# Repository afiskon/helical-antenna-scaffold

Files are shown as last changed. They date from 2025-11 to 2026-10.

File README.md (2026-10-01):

# Helical Antenna Scaffold and Calculator

This is a fork of 3D printable helical antenna scaffold implemented
by [@sgcderek][1] in 2021-2023.

One major difference from the original is that this project has a built-in
helical antenna calculator. The calculation method is based on the
[book by Igor, DL2KQ][2]. You only specify the desired frequency and optionally
other parameters. The math is done by OpenSCAD.

Besides that you can specify as many struts as you want and make them
symmetrical along the Z axis. This is useful when printing large antennas
in two or more parts and then gluing them.

Also this repository includes:

* An antenna cover and LNB mount for QO-100 operation. The models are
  optimized for Bullseye LNB.
* Reflector model for helicone antenna, designed according to the paper
  [Design of Optimal Ground Conductor for the Helical Antenna][3].

Note that optimal parameters for helicone and helical antenna differ.
See the list of related articles, particularly #5.

Related articles (in Russian):

1. https://eax.me/2025/2025-10-20-helical-antenna.html
2. https://eax.me/2025/2025-11-21-qo-100-tx.html
3. https://eax.me/2026/2026-08-05-helicone-antenna.html
4. https://eax.me/2026/2026-09-02-meteor-m2-hrpt.html
5. https://eax.me/2026/2026-09-09-helicone-antenna-modeling.html
6. https://eax.me/2026/2026-09-16-metop.html

[1]: https://github.com/sgcderek
[2]: http://dl2kq.de/ant/kniga/1345.htm
[3]: http://home.etf.rs/~milanilic/publications/papers/Djordjevic-Etran06.pdf

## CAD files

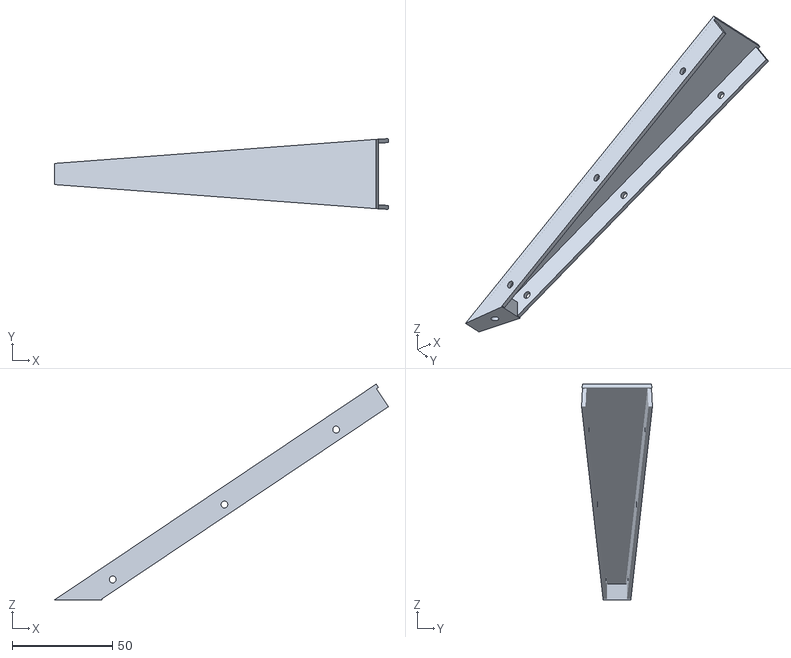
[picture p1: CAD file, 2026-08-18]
stl-files/meteor-m2/helicone-reflector-1700mhz.stl
166.2 x 35.3 x 107.4

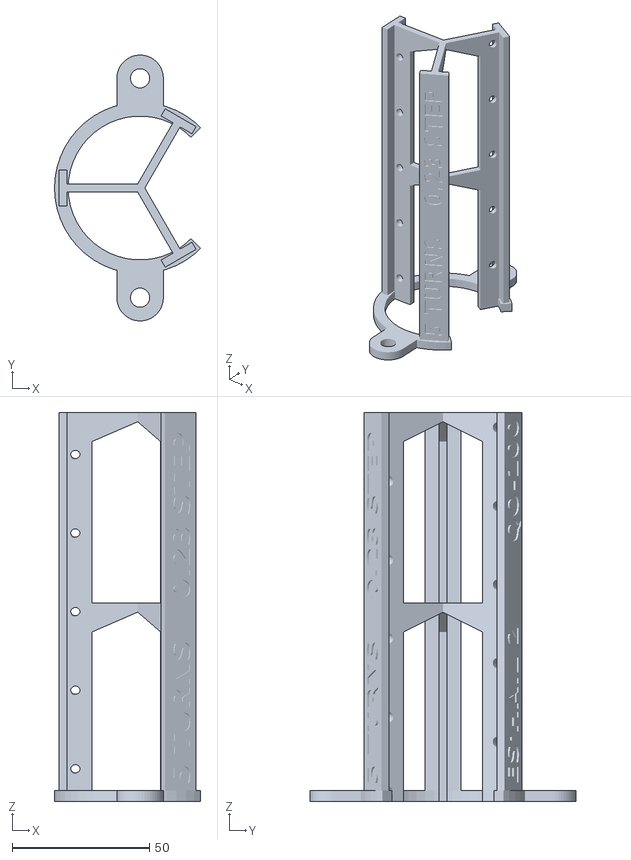
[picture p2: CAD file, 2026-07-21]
stl-files/qo-100/scaffold-qo-100.stl
53.3 x 97.0 x 141.9

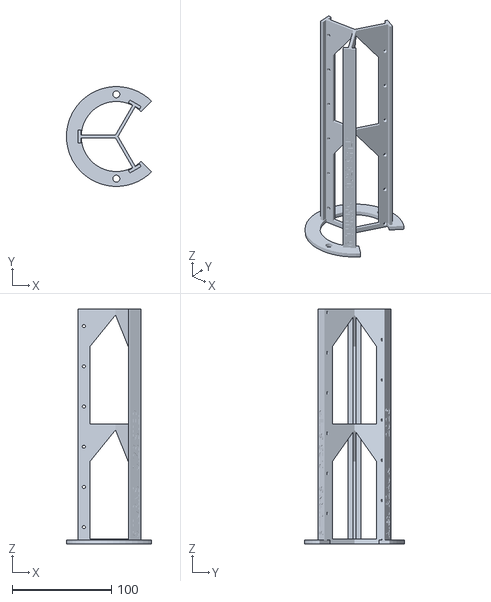
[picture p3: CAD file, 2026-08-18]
stl-files/meteor-m2/helical-antenna-1700mhz.stl
85.9 x 100.5 x 236.9

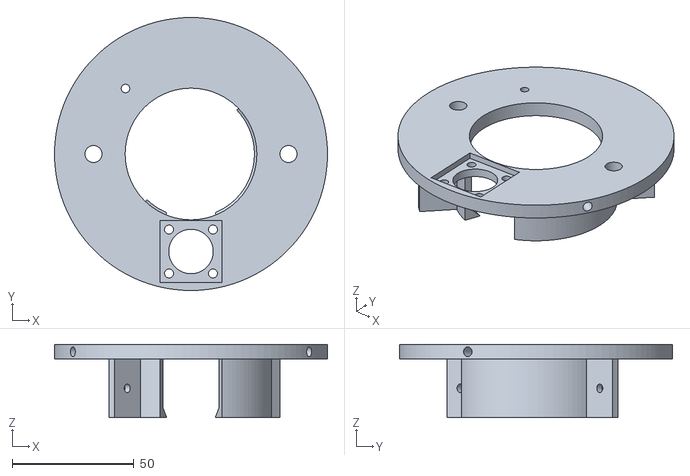
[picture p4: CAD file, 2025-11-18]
stl-files/qo-100/base.stl
112.0 x 112.0 x 30.0

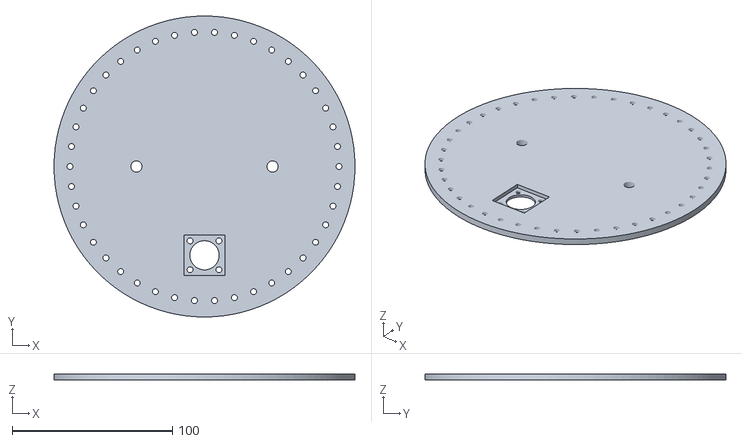
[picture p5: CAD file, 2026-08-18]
stl-files/meteor-m2/helicone-base-1700mhz.stl
187.8 x 187.8 x 4.00

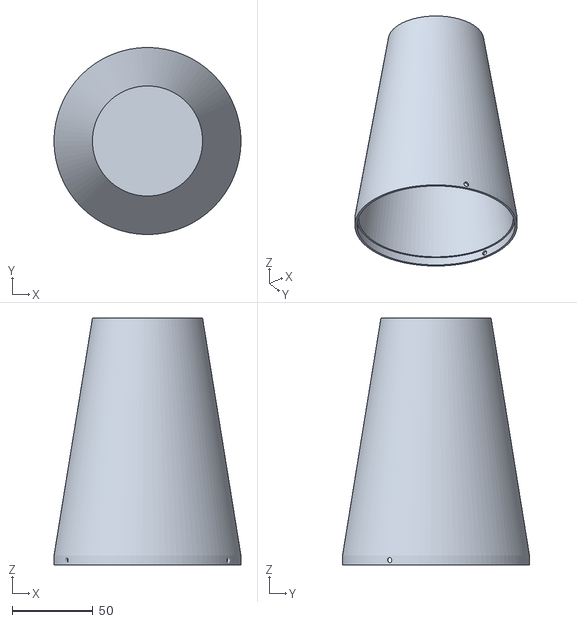
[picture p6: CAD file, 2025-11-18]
stl-files/qo-100/cover.stl
115.4 x 115.4 x 152.5

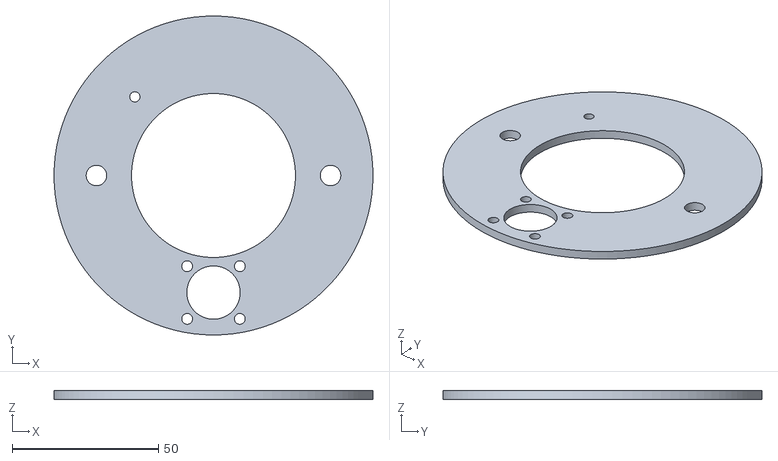
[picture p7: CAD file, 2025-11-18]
stl-files/qo-100/cutting-template.stl
109.0 x 109.0 x 3.00

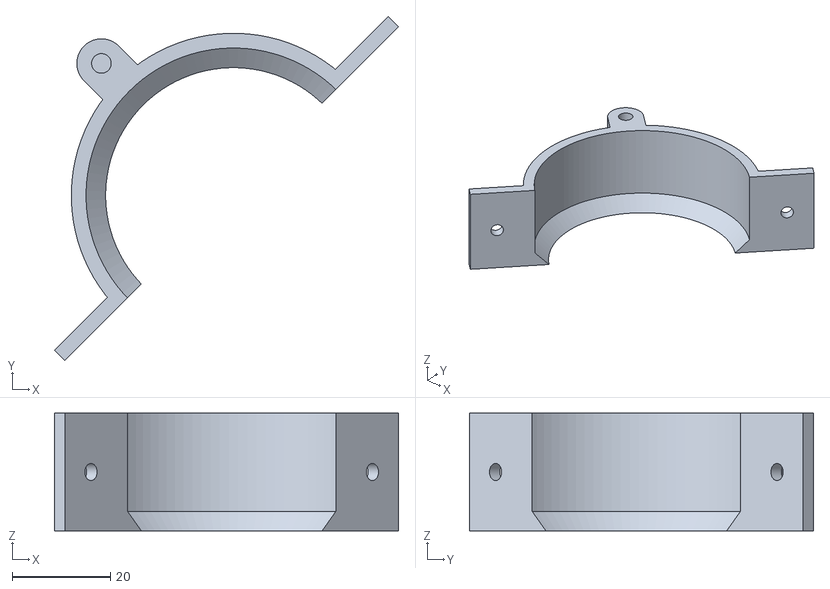
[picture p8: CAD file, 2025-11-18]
stl-files/qo-100/clamp.stl
70.0 x 70.0 x 24.0

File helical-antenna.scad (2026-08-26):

/*
 * dereksgc customizable helical antenna scaffold v5
 *   https://github.com/sgcderek/dsgc-helix-scaffold/
 *
 * Modified by Alex, R2AUK
 *   https://github.com/afiskon/helical-antenna-scaffold
 */

/* [Basic settings] */

// Operating frequency of the helix (MHz)
Frequency = 2450;

// Spacing between turns (wl)
Spacing = 0.23; // [0.22..0.24]

// Number of turns of the helix
Turns = 5; // [3..25]

// Vertical offset of the first (bottom) hole (mm)
Bottom_hole_offset = 2.5;

// Polarization of the helix
Polarization = "LHCP"; //[RHCP,LHCP]

// Diameter of the holes for the helix conductor (mm)
Cutout_diameter = 3.5;

// Face number (OpenSCAD/Customizer parameter)
$fn = 50;

/* [Leg settings] */

// Width of the inner leg wall (mm)
Inner_leg_width = 3;

// Width of the outer leg wall (mm)
Outer_leg_width = 13;

// Distance between inner and outer leg walls (mm)
Leg_wall_distance = 12;

// Type of leg cross-section to extrude
Leg_type = "T-Beam"; //[Trapezoid,T-Beam,H-Beam]

/* [Base settings] */

// Base width (mm)
Base_width = 5;

// Base thickness (mm)
Base_thickness = 4;

// Cut out a third of the base (space for matching, connector, etc.)
Enable_cutout = true;

/* [Strut settings] */

// Angle at which struts are generated (deg)
Strut_angle = 60;

// Generate a strut at the base of the scaffold
Bottom_strut = true;

// How much to shift the bottom strut up (mm)
Bottom_strut_offset = 0;

// Total number of struts above the base (minimum 1, top strut is included)
Struts_number = 2;

// Make middle struts symmetrical along the Z axis with X-shaped overhangs
Symmetrical_struts = false;

// Generate a strut at the top of the scaffold (recommended for most scaffolds)
Top_strut = true;

// How much to shift the top strut down (mm)
Top_strut_offset = 0;

/* [Mounting settings] */

// Distance between the two mounting holes (mm)
Mounting_separation = 70;

// Diameter of the mounting holes (mm)
Mounting_diameter = 7;

// Thickness of the rim around each mounting hole (mm)
Mounting_thickness = 5;

// Rotational offset of the mounting holes (deg)
Mounting_rotation = 0;

/* [Text settings] */

// Enable engraved ID and decoration text
Enable_text = true;

// Custom decoration text (set to none to disable)
Decoration_text = "Alex R2AUK        2026";

// Depth of the text engraving (mm)
Text_depth = 0.75;

// Modifies the size of the text (can be lowered if text is too long)
Text_size_multiplier = 0.8;

/* [Hidden] */

// Polarization modifier (RHCP = 1, LHCP = -1)
Pol_modifier = (Polarization == "RHCP") ? 1 : -1;

// Speed of light (m/s)
C = 299792458;

// Wavelength of the helix frequency (mm)
Wavelength = C/Frequency/1000;

// Gain and diameter are determined using approximations of the plots
// provided by Igor, DL2KQ http://dl2kq.de/ant/kniga/1345.htm
Gain = (-0.18*pow(Turns, 2) + 0.57*Turns - 12.63) * exp(-0.16 * Turns) + 19;
echo(str("Approximate gain: ", ceil(Gain * 10) / 10, " dBi"));

// Diameter of the helix (wl)
Diameter_wl = ceil((0.2467 * pow(Turns, -0.2666) + 0.2172)*1000)/1000;

// Diameter of the helix (mm)
Diameter = ceil(Wavelength * Diameter_wl * 10) / 10;
echo(str("Helix diameter: ", Diameter_wl, " wl, ", Diameter, " mm"));

Wire_length = ceil(Diameter * PI * Turns);
echo(str("Approximate wire length: ", Wire_length, " mm"));

Refl_round_dia = ceil(0.8 * Wavelength);
echo(str("Round reflector diameter: ", Refl_round_dia, " mm"));

Refl_square_size = ceil(1.1 * Wavelength);
echo(str("Square reflector size: ", Refl_square_size, " mm"));

ra_to_wire_dia_wl = [
    [240, 0.005],
    [190, 0.01],
    [140, 0.02],
    [115, 0.03],
    [87,  0.04],
    [75,  0.05],
    [50,  0.07],
];

for(item = ra_to_wire_dia_wl) {
    ra = item[0];
    dia = ceil(item[1] * Wavelength * 10)/10;
    echo(str("Wire diameter for ", ra, " Ohm input impedance: ", dia, " mm"));
}

// Distance between turns (mm)
Spacing_distance = Wavelength*Spacing;

// Circumference of the helix (mm)
Circumference = PI*Diameter;

// Helix pitch (deg)
Pitch = atan(Spacing_distance/Circumference)*Pol_modifier;

// Calculate total number of segments in helix
Total_segments = Turns * 3;

// Calculate the length of each segment (slightly longer than longest leg dimension, mm)
Segment_height = max(Inner_leg_width, Outer_leg_width)*1.1;

// Calculate offset of the bottom corner of the strut base from the desired overhang angle
Strut_offset = ((Diameter/2)/tan(Strut_angle))-Leg_wall_distance/2;

// Total scaffold height (mm)
Total_height = Bottom_hole_offset + Turns * Spacing_distance + Cutout_diameter * 1.5;

echo(str("Total scaffold height: ", Total_height, " mm"));

// Thicknes of the top part of each strut (mm)
Strut_thickness = 3; // Total_height;

// Font used for the text on the leg
Text_font = "DejaVu Sans:style=Bold";

// Size of the text
Text_size = Outer_leg_width*0.75*Text_size_multiplier;

// Frequency text
Text_frequency = str(Frequency, " MHz          ", Polarization /*, " ", Material*/);

// Diameter, Pitch
Text_ID = str("Dia ", round(Diameter_wl*100)/100, "   Pitch ", round(Spacing*100)/100);

// Difference between legs and leg cutouts
difference(){
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

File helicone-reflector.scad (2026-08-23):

F_MHz = 2450;
Lambda_mm = (299792458 / (F_MHz*1000000))*1000;
max_width = 25;       // Maximum allowed width of the larger trapezoid base (mm)

mounting_holes_dia = 7;   // see helical-antenna.scad, Mounting_diameter
mounting_separation = 70; // see helical-antenna.scad, Mounting_separation

// Make sure the bottom N-gon does not collapse inside the D1 circle
// The value 10 works OK for F_MHz in 1691..2450 range
// Set to 0 if preserving ideal cone angles is more important
d1_correction = 10;

// You can also experiment with D2 correction
// Personally I doubt that it affects much the overall antenna gain
d2_correction = 0;

D1 = Lambda_mm*0.782 + d1_correction; // Bottom diameter (mm)
D2 = Lambda_mm*2.604 + d2_correction; // Top diameter (mm, D2 > D1)
H = Lambda_mm*0.6;    // Cone height (mm)
t = 2;                // Wall and flange thickness (mm)

gap = 0.1;        // Gap between adjacent trapezoid segments (mm)
eps = 0.05;       // Small overlap for clean CSG boolean operations

// Side Flange Parameters
flange_w = 10;    // Side flange width (mm)
screw_d  = 3.5;   // Side screw hole diameter (mm, for M3)
edge_offset = 28;  // Offset from edges to outer holes (mm)
flange_inset = 1.5; // Radial inset towards Z-axis for full wall intersection (mm)

// Bottom Outer Mount Flange Parameters
bottom_h = 8;            // Height/thickness of the bottom mounting flange (mm)
bottom_flange_w = 20;    // Width of the bottom flange extending outward (mm)
insert_d = 3.7;          // Hole diameter for heat-set insert (mm)

$fn = 100;

// =================================================================
// GEOMETRY CALCULATIONS
// =================================================================

ratio = min(1, max_width / D2);
N_calc = ceil(180 / asin(ratio));
N = max(3, N_calc);
step_angle = 360 / N;

echo(str("Calculated number of facets N = ", N));

alpha = atan((D2 - D1) / (2 * H)); // Wall tilt angle relative to vertical
t_rad = t / cos(alpha);            // Radial thickness of the wall

half_angle = step_angle / 2;

// =================================================================
// MODULES
// =================================================================

// Main trapezoidal wall segment of the cone
module main_wall_segment() {
    r1_out = D1 / 2;
    r1_in  = r1_out - t_rad;
    r2_out = D2 / 2;
    r2_in  = r2_out - t_rad;

    // Angular shift to compensate for the gap
    d_ang_1 = (gap / 2) / (r1_out * 180 / PI);
    d_ang_2 = (gap / 2) / (r2_out * 180 / PI);

    a1_R = -half_angle + d_ang_1;
    a1_L =  half_angle - d_ang_1;
    a2_R = -half_angle + d_ang_2;
    a2_L =  half_angle - d_ang_2;

    // Extend the INNER face to match full slant_len (where side_flange ends),
    // keeping the outer face at H so the top cut remains exactly 90 deg to the print bed.
    dh_in = t_rad * sin(alpha) * cos(alpha);
    dr_in = t_rad * pow(sin(alpha), 2);

    z_top_in  = H + dh_in;
    r2_top_in = r2_in + dr_in;

    pts = [
        // Bottom base (z = 0)
        [ r1_out * cos(a1_R), r1_out * sin(a1_R), 0 ], // 0
        [ r1_out * cos(a1_L), r1_out * sin(a1_L), 0 ], // 1
        [ r1_in  * cos(a1_L), r1_in  * sin(a1_L), 0 ], // 2
        [ r1_in  * cos(a1_R), r1_in  * sin(a1_R), 0 ], // 3

        // Top base (Outer at H, Inner extended to match side_flange)
        [ r2_out    * cos(a2_R), r2_out    * sin(a2_R), H ],        // 4: Outer Right
        [ r2_out    * cos(a2_L), r2_out    * sin(a2_L), H ],        // 5: Outer Left
        [ r2_top_in * cos(a2_L), r2_top_in * sin(a2_L), z_top_in ], // 6: Inner Left (Extended)
        [ r2_top_in * cos(a2_R), r2_top_in * sin(a2_R), z_top_in ]  // 7: Inner Right (Extended)
    ];

    faces = [
        [0, 1, 5, 4], // Outer face
        [2, 3, 7, 6], // Inner face
        [0, 4, 7, 3], // Right side cut
        [1, 2, 6, 5], // Left side cut
        [0, 3, 2, 1], // Bottom face
        [4, 5, 6, 7]  // Top face
    ];

    polyhedron(points = pts, faces = faces);
}

// Side mounting flange (ear) with screw holes
module side_flange(side = 1) { // side: 1 - left joint, -1 - right joint
    slant_len = sqrt(pow(H, 2) + pow((D2 - D1) / 2, 2));
    
    holes_z = [
        edge_offset,
        slant_len / 2,
        slant_len - edge_offset
    ];

    intersection() {
        // Crop strictly within Z = [0, H]
        cylinder(r = D2 * 2, h = H, $fn = 4);

        // Align with the joint plane
        rotate([0, 0, side * half_angle]) {
            // Shift towards center by flange_inset to ensure solid intersection
            translate([(D1 / 2) - flange_inset, 0, 0])
                rotate([0, alpha, 0]) {
                    
                    y_trans = (side == 1) ? (-t - gap / 2) : (gap / 2);

                    difference() {
                        // Flange block
                        translate([-eps, y_trans, 0])
                            cube([flange_w + flange_inset + eps, t, slant_len]);

                        // Screw holes
                        for (z_pos = holes_z) {
                            translate([flange_w / 2 + flange_inset, y_trans - eps, z_pos])
                                rotate([-90, 0, 0])
                                    cylinder(d = screw_d, h = t + 2 * eps);
                        }
                    }
                }
        }
    }
}

// Bottom mounting flange extending OUTWARD with heat-set insert hole
module bottom_mount_flange() {
    r1_out = D1 / 2;
    r_ext  = r1_out + bottom_flange_w;
    
    // Position of the insert hole (centered in the outward tab)
    hole_radius = r1_out + (bottom_flange_w / 2);

    // Calculate angular limits matching the bottom gap
    d_ang = (gap / 2) / (r1_out * 180 / PI);
    a_right = -half_angle + d_ang;
    a_left  =  half_angle - d_ang;

    // Radius at height bottom_h along the outer tilted face
    r_outer_at_bottom_h = r1_out + bottom_h * tan(alpha);

    difference() {
        // Outward tab sector starting from the outer wall surface (r1_out - eps)
        polyhedron(
            points = [
                // Inner points embedded slightly into the outer wall surface
                [(r1_out - eps) * cos(a_right), (r1_out - eps) * sin(a_right), 0],
                [(r1_out - eps) * cos(a_left),  (r1_out - eps) * sin(a_left),  0],
                [(r_outer_at_bottom_h - eps) * cos(a_left),  (r_outer_at_bottom_h - eps) * sin(a_left),  bottom_h],
                [(r_outer_at_bottom_h - eps) * cos(a_right), (r_outer_at_bottom_h - eps) * sin(a_right), bottom_h],

                // Outer points (extending outwards)
                [r_ext * cos(a_right), r_ext * sin(a_right), 0],
                [r_ext * cos(a_left),  r_ext * sin(a_left),  0],
                [r_ext * cos(a_left),  r_ext * sin(a_left),  bottom_h],
                [r_ext * cos(a_right), r_ext * sin(a_right), bottom_h]
            ],
            faces = [
                [0, 1, 2, 3], // Inner face (matches outer wall slope)
                [4, 7, 6, 5], // Outer face
                [0, 4, 5, 1], // Bottom face
                [3, 2, 6, 7], // Top face
                [0, 3, 7, 4], // Right side
                [1, 5, 6, 2]  // Left side
            ]
        );

        // Vertical hole for heat-set insert
        translate([hole_radius, 0, -eps])
            cylinder(d = insert_d, h = bottom_h + 2 * eps);
    }
}

// Complete solid segment module
module full_trapezoid_segment() {
    union() {
        main_wall_segment();
        side_flange(side = 1);  // Left side flange
        side_flange(side = -1); // Right side flange
        bottom_mount_flange();  // Bottom outer flange with heat-set insert hole
    }
}

module typen_holes() {
    typen_center = 18.2;
    typen_screw_hole = 3.7;
    typen_screw_hole_offset = 18/2;
    typen_height = 10;
    typen_deepening = 2.5;

    cylinder(d = typen_center, h = typen_height, center = true);
    translate([typen_screw_hole_offset, typen_screw_hole_offset, 0])
        cylinder(d = typen_screw_hole, h = typen_height, center = true);
    translate([typen_screw_hole_offset, -typen_screw_hole_offset, 0])
        cylinder(d = typen_screw_hole, h = typen_height, center = true);
    translate([-typen_screw_hole_offset, typen_screw_hole_offset, 0])
        cylinder(d = typen_screw_hole, h = typen_height, center = true);
    translate([-typen_screw_hole_offset, -typen_screw_hole_offset, 0])
        cylinder(d = typen_screw_hole, h = typen_height, center = true);
}

module base() {
    translate([0, 0, -30]) difference() {
        cylinder(d = D1 + 2*bottom_flange_w, h = t*2, center = true);

        translate([0, -(D1 - d1_correction)/2 + 25/2 + 1, 0]) {
            typen_holes();
            translate([0, 0, (t*2)/2 + 2.5/2 - 2.5 + eps])
                cube([25.5, 25.5, 2.5], center=true);
        }
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

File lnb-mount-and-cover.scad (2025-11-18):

$fn = 100;
eps = 0.01;

show_base = true;
show_base_clamp = true;
show_cover = true;
show_cutting_template = true;

base_clamp_screw_offset = 8;

typen_center = 18.2;
typen_screw_hole = 3.7;
typen_screw_hole_offset = 18/2;
typen_height = 10;
typen_deepening = 2.5;

lnb_mount_d = 60;
lnb_mount_t = 3;
lnb_mount_angle_size = 4;
lnb_mount_h = 24; /* including lnb_mount_angle_size! */

mount_cutoff_angle = 45;

base_dia = 112;
base_t = 6;
base_hole_dia = 54;

mounting_holes_dia = 7;
mounting_separation = 80;

side_hole_d = 4;
side_hole_t = 7;

cover_t = 1.5;
cover_sp = 0.2;
cover_h = 145;
cover_top_dia = 65;

module typen_holes() {
    cylinder(d = typen_center, h = typen_height, center = true);
    translate([typen_screw_hole_offset, typen_screw_hole_offset, 0])
        cylinder(d = typen_screw_hole, h = typen_height, center = true);
    translate([typen_screw_hole_offset, -typen_screw_hole_offset, 0])
        cylinder(d = typen_screw_hole, h = typen_height, center = true);
    translate([-typen_screw_hole_offset, typen_screw_hole_offset, 0])
        cylinder(d = typen_screw_hole, h = typen_height, center = true);
    translate([-typen_screw_hole_offset, -typen_screw_hole_offset, 0])
        cylinder(d = typen_screw_hole, h = typen_height, center = true);
}

module mount_base(right = false, left = false) {
    rotate([0, 180, 0]) intersection() {

        union() {
            if(right)
                translate([0, 100/2, 0])
                    cube([100, 100, lnb_mount_h+eps], center = true);
            
            if(left)
                translate([0, -100/2, 0])
                    cube([100, 100, lnb_mount_h+eps], center = true);
        }
    
        difference() {
            union() {
                difference() {
                    union() {
                        cylinder(d = lnb_mount_d + 2*lnb_mount_t, h = lnb_mount_h, center = true);
                        
                        cube([lnb_mount_d + 2*lnb_mount_t + 15*2, 2*lnb_mount_t+1, lnb_mount_h], center = true);
                    }
                    cylinder(d = lnb_mount_d, h = lnb_mount_h+eps, center = true);

                    
                    translate([lnb_mount_d/2+lnb_mount_t+15/2, 0, 0]) rotate([90, 0, 0])
                        cylinder(h = 100, d = 3.5, center = true);
                    translate([-lnb_mount_d/2-lnb_mount_t-15/2, 0, 0]) rotate([90, 0, 0])
                        cylinder(h = 100, d = 3.5, center = true);
                }
        
                translate([0,0, lnb_mount_h/2-lnb_mount_angle_size/2]) difference() {
                    cylinder(d = lnb_mount_d + eps, h = lnb_mount_angle_size, center = true);
                    cylinder(d1 = lnb_mount_d + eps, d2 = lnb_mount_d - 2*lnb_mount_angle_size, h = lnb_mount_angle_size+eps, center = true);
                }
    
            }
            
            cube([lnb_mount_d + 2*lnb_mount_t + 15*2+eps, 1, lnb_mount_h+eps], center = true);
        }
    }
}

/* COVER */
if(show_cover) {
    union() {
        translate([0, 0, base_t/2]) difference() {
            cylinder(d = base_dia+2*cover_t+2*cover_sp, h = base_t, center = true);
            cylinder(d = base_dia+2*cover_sp, h = base_t+eps, center = true);
            
            for(i = [0:2])
                rotate([0, 0, 120*i])
                    translate([0, base_dia/2+eps, 0])
                        rotate([90, 0, 0])
                            translate([0, 0, -side_hole_t/2])
                                cylinder(d = 3.5, h = side_hole_t);
        }
        
        translate([0, 0, (cover_h+cover_t)/2+base_t-eps]) difference() {
            cylinder(h = cover_h+cover_t, d1 = base_dia+2*cover_t+2*cover_sp, d2 = cover_top_dia+2*cover_t, center = true);
            
            translate([0, 0, -cover_t/2-eps]) cylinder(h = cover_h, d1 = base_dia-2, d2 = cover_top_dia, center = true);
        }
    }
}

/* BASE */
if(show_base) {
    union() {
        translate([0, 0, base_t/2-eps]) difference() {
            cylinder(d = base_dia, h = base_t, center = true);
            cylinder(d = base_hole_dia, h = base_t+eps, center = true);
            
            translate([0, -lnb_mount_d/2-lnb_mount_t-7, 0])
                union() {
                    typen_holes();
                    
                    /* A deepening for type-N connector */
                    translate([0, 0, lnb_mount_t-typen_deepening/2+eps])
                        cube([25.5, 25.5, typen_deepening], center = true);
                }
            translate([mounting_separation/2, 0, 0])
                cylinder(d = mounting_holes_dia, h = 100, center = true);
            translate([-mounting_separation/2, 0, 0])
                cylinder(d = mounting_holes_dia, h = 100, center = true);
            
            rotate([0, 0, 45]) translate([0, lnb_mount_d/2+base_clamp_screw_offset, 0])    
                cylinder(d = 3.5, h = base_t+eps, center = true);
            
            for(i = [0:2])
                rotate([0, 0, 120*i])
                    translate([0, base_dia/2-side_hole_t/2+eps, 0])
                        rotate([90, 0, 0])
                            translate([0, 0, -side_hole_t/2])
                                cylinder(d = side_hole_d, h = side_hole_t);
        }
        
        translate([0, 0, -lnb_mount_h/2+eps]) difference() {
            rotate([0, 0, 45]) mount_base(left = true);
            
            rotate([0, 0, -mount_cutoff_angle/2-90]) translate([0, 0, -lnb_mount_h/2-eps/2])
                rotate_extrude(angle = mount_cutoff_angle)
                    polygon([[0, 0], [0, lnb_mount_h+eps], [100, lnb_mount_h+eps], [100, 0]]);
        }
    }
}

/* CUTTING TEMPLATE */
if(show_cutting_template) {
    translate([0, 0, -30]) difference() {
        cylinder(d = base_dia-3, h = base_t/2, center = true);
        cylinder(d = base_hole_dia+2, h = base_t/2+eps, center = true);
        
        translate([0, -lnb_mount_d/2-lnb_mount_t-7, 0])
            typen_holes();
        translate([mounting_separation/2, 0, 0])
            cylinder(d = mounting_holes_dia, h = 100, center = true);
        translate([-mounting_separation/2, 0, 0])
            cylinder(d = mounting_holes_dia, h = 100, center = true);
        
        rotate([0, 0, 45]) translate([0, lnb_mount_d/2+base_clamp_screw_offset, 0])    
            cylinder(d = 3.5, h = base_t+eps, center = true);
    }
} 

/* BASE CLAMP */
if(show_base_clamp) {
    translate([0, 0, -lnb_mount_h/2+eps])
        rotate([0, 0, 45])
            difference() {
                union() {
                    mount_base(right = true);
                    
                    translate([0, lnb_mount_d/2+base_clamp_screw_offset, 0])
                        cylinder(d = 10, h = lnb_mount_h, center = true);
                   
                    /* some hackery here... */
                    translate([0, lnb_mount_d/2+5, 0])
                        cube([10, 6, lnb_mount_h], center = true);
                }
                
                translate([0, lnb_mount_d/2+base_clamp_screw_offset, lnb_mount_h/2])
                    cylinder(d = 4, h = lnb_mount_h, center = true);
            }
}

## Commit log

2025-09-16 Imlement helical antenna calculator
    [dsgc_helix_v3.scad, dsgc_helix_v4.scad, helical-antenna.scad]
2025-09-22 Add more comments for Parallel_turn
    [helical-antenna.scad]
2025-09-22 Minor changes
    [helical-antenna.scad]
2025-09-28 Get rid of useless Scaffold_color
    [helical-antenna.scad]
2025-11-18 Move lnb-mount-and-cover/ from a sandbox repository
    [base.stl, clamp.stl, cover.stl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]
2026-07-21 Add helicone antenna reflector
    [base.stl, clamp.stl, cover.stl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]
2026-08-01 Improve helicone-reflector.scad
    [helicone-reflector-2450mhz-full.stl, helicone-reflector-2450mhz-part-1.stl, helicone-reflector-2450mhz-part-2.stl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]
2026-08-01 helicone-reflector.scad: fix little D1 mismatch
    [helicone-reflector-2450mhz.stl, helicone-reflector.scad, holes-template-2450mhz.stl]
2026-08-03 helicone-reflector.scad: minor changes
    [helicone-reflector.scad]
2026-08-03 helicone-reflector.scad: remove little overhang
    [helicone-reflector-2450mhz.stl, helicone-reflector.scad]
2026-08-09 helical-antenna.scad: print total scaffold height
    [helical-antenna.scad]
2026-08-09 helicone-reflector.scad: module holes_template() -> module base()
    [helicone-reflector.scad]
2026-08-09 helicone-reflector: update STLs
    [base-2450mhz.stl, helicone-reflector-2450mhz.stl, helicone-reflector.scad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]
2026-08-10 helicone-reflector.scad: minor corrections
    [base-2450mhz.stl, helicone-reflector-2450mhz.stl, helicone-reflector.scad]
2026-08-12 helicone-reflector.scad: fix comments
    [helicone-reflector.scad]
2026-08-18 Rearrange the structure of stl-files/
    [base-2450mhz.stl, base.stl, clamp.stl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]
2026-08-18 stl-files/meteor-m2: actually the antenna ended up being tuned to 1700 mhz
    [helical-antenna-1700mhz.stl, helicone-base-1700mhz.stl, helicone-reflector-1700mhz.stl]
2026-08-23 helicone-reflector.scad: add code for a round reflector
    [helicone-reflector.scad]
2026-08-26 Middle_strut = true|false --> Struts_number = N
    [helical-antenna.scad]
2026-08-26 New variable: Symmetrical_struts = true|false
    [helical-antenna.scad]
2026-08-26 helical-antenna.scad: refactoring, Turns specifies the exact/actual turns number now
    [helical-antenna.scad]
2026-08-26 helical-antenna.scad: render diameter and pitch (number of turns is easy to figure out...)
    [helical-antenna.scad]
2026-09-09 Revise README with updated title and notes
    Updated project title and added important notes regarding helical and helicone antennas. Included additional reference links for modeling.
2026-10-01 Clarify note on helicone and helical antenna parameters
    Rephrase warning about optimal parameters for antennas.
